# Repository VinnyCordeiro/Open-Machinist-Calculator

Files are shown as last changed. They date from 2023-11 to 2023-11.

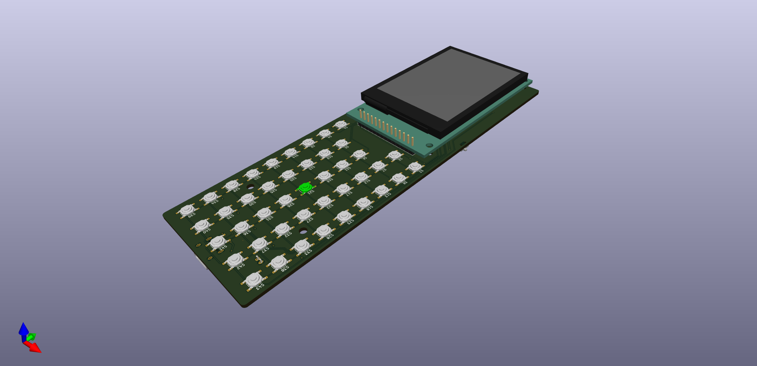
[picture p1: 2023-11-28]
documentation/Open_Machinist_Calculator.png

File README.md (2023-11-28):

# Open-Machinist-Calculator
Open Machinist Calculator, an open source hardware version of the Machinist Calc™ Pro calculator by Calculated Industries®

### FAQ
* ***Why?***

Because I'm interested in learning machining and that already-available calculator is too expensive for a hobbyist like me. So the idea is research all the formulas, code them in the calculator, and use it when needed.

* ***Why have you chosen the CERN Open Hardware Licence?***

Because as much as I love the GPL, it was created for Open Source **Software**. Open Source Hardware is an entirely different beast, with very different concerns and needs to be attended, there's even an [article](https://www.gnu.org/philosophy/free-hardware-designs.en.html) concerning that on the GNU website.

### TODO
* Start the code for real instead of a place holder. That also means researching all the formulas for each function, both for metric and imperial measurements. That'll be fun. 🙃
* Create a separate repository for the code and license under the GPL v3, the CERN licence is just for the hardware.
* The case is by no means water/dust proof, and that can be a huge problem with metallic dust from machining. That's something that needs improvement.

### UPDATES
November 28th, 2023: Initial public release.

<hr />
<table border="0px">
<th align="left">
&copy; Open Machinist Calculator 2023.
</th>
<tr>
<td>
This documentation describes Open Hardware and is licensed under the CERN Open Hardware Licence version 2 - Strongly Reciprocal.
</td>
</tr>
<tr>
<td>
You may redistribute and modify this documentation under the terms of the
CERN-OHL-S v2. (http://ohwr.org/cernohl). This documentation is distributed
WITHOUT ANY EXPRESS OR IMPLIED WARRANTY, INCLUDING OF
MERCHANTABILITY, SATISFACTORY QUALITY AND FITNESS FOR A
PARTICULAR PURPOSE. Please see the CERN-OHL-S v2 for applicable
conditions.
</td>
</tr>
</table>

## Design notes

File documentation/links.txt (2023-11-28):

Raspberry Pi Pico -- 4x4 Matrix Keypad and 1602 LCD Interface
https://www.instructables.com/Raspberry-Pi-Pico-4x4-Matrix-Keypad-and-1602-LCD-I/

Use Matrix Keypad with Raspberry PI Pico to get User Codes Input
https://peppe8o.com/use-matrix-keypad-with-raspberry-pi-pico-to-get-user-codes-input/

Raspberry Pi Pico Interrupts & Button Interfacing Tutorial Using MicroPython.
https://electrocredible.com/raspberry-pi-pico-external-interrupts-button-micropython/

ILI9341 TFT display with Arduino
https://electronoobs.com/eng_arduino_tut58.php

Color 320x240 TFT Touchscreen, ILI9341 Controller Chip (for reference)
https://www.pjrc.com/store/display_ili9341_touch.html

Arduino Calculator
https://projecthub.arduino.cc/123samridhgarg/arduino-calculator-bce0df

Arduino Calculator Using 4X4 Keypad 
https://www.instructables.com/Arduino-Calculator-Using-4X4-Keypad/

How to Make a Simple Arduino Uno Calculator
https://linuxhint.com/make-simple-calculator-arduino-uno/

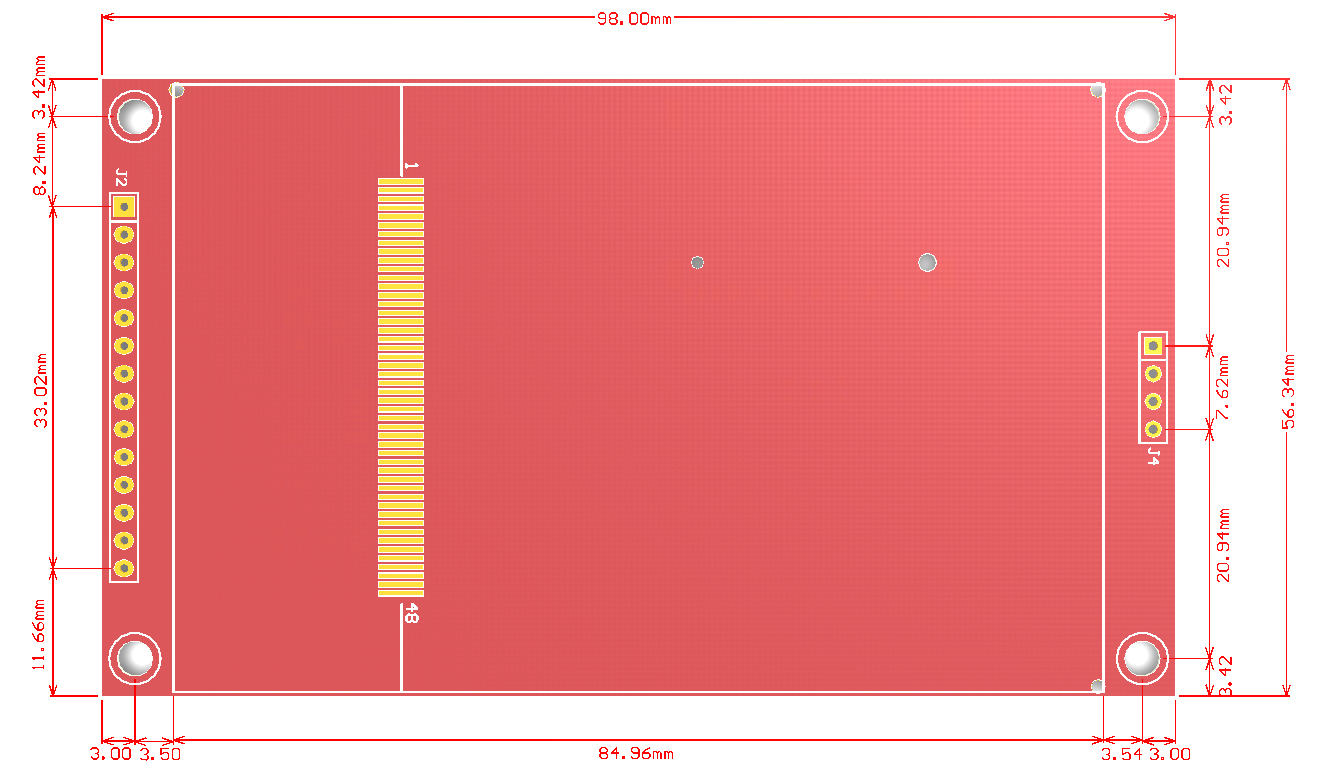
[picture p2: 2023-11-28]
documentation/elecrow-35inch-480x320-mcu-spi-serial-tft-lcd-module-display-dime.jpg

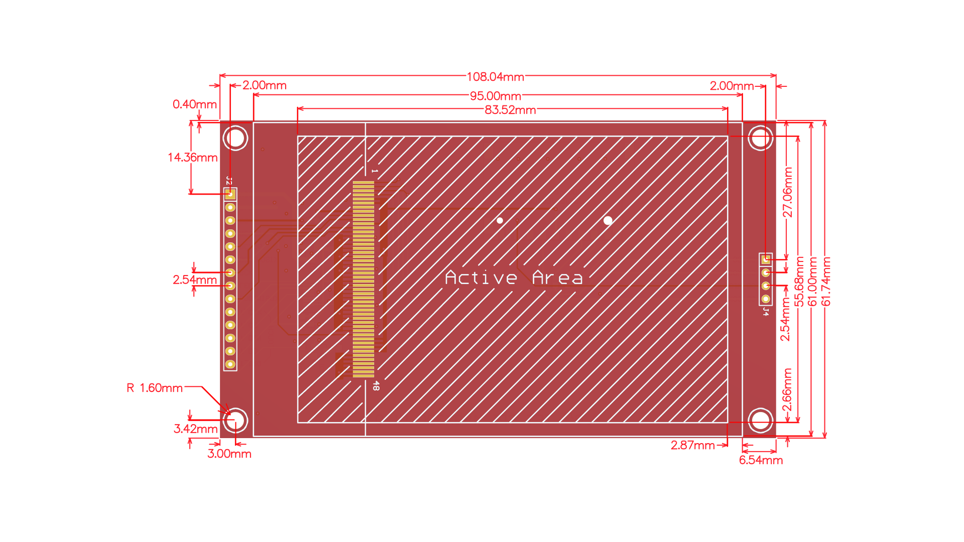
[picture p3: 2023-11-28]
documentation/4.0in_module.png

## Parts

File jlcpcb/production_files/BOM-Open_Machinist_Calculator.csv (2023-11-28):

Comment | Designator | Footprint | LCSC
0.1uF | C10,C12,C13,C18,C6,C7,C8,C9 | C_0603_1608Metric | C14663
MCP73831 | U4 | SOT-23-5 | C14879
1uF | C11,C14 | C_0603_1608Metric | C15849
10µF | C3,C4 | C_0805_2012Metric_Pad1.18x1.45mm_HandSolder | C15850
HRO-TYPE-C-31-M-12 | J1 | HRO-TYPE-C-31-M-12-HandSoldering | C165948
10k | R1,R14,R2,R3,R4,R5,R9 | R_0805_2012Metric_Pad1.20x1.40mm_HandSolder | C17414
0 | R8 | R_0805_2012Metric_Pad1.20x1.40mm_HandSolder | C17477
300k | R10,R11 | R_0805_2012Metric_Pad1.20x1.40mm_HandSolder | C17616
4.7µF | C5 | C_0805_2012Metric_Pad1.18x1.45mm_HandSolder | C1779
10uF | C15 | C_0603_1608Metric | C19702
RP2040 | U3 | QFN-56_EP_7x7_Pitch0.4mm | C2040
1K | R12,R17 | R_0603_1608Metric | C21190
LED_CHR | D2 | LED_0603_1608Metric | C2286
2K | R15 | R_0603_1608Metric | C22975
SW_RESET | SW1 | SW_SPST_B3U-1000P | C231329
27R | R18,R19 | R_0603_1608Metric | C25190
10K | R13,R20 | R_0603_1608Metric | C25804
AP2301B | Q2 | SOT-23-3 | C2763847
5.1k | R6,R7 | R_0805_2012Metric_Pad1.20x1.40mm_HandSolder | C27834
USBLC6-2P6 | U1 | SOT-666 | C2827693
1µF | C1 | C_0805_2012Metric_Pad1.18x1.45mm_HandSolder | C28323
~ | S1,S10,S11,S12,S13,S14,S15,S16,S17,S18,S19,S2,S20,S21,S22,S23,S24,S25,S26,S27,S28,S29,S3,S30,S31,S32,S33,S34,S35,S36,S37,S38,S39,S4,S40,S41,S42,S5,S6,S7,S8,S9 | TL3342 | C2886898
W25Q64JV | U5 | WSON-8-1EP_6x5mm_P1.27mm_EP3.4x4mm | C2940197
XC6220B331MR | U2 | SOT-23-5 | C3040644
12pF | C16,C17 | C_0603_1608Metric | C38523
100nF | C2 | C_0805_2012Metric_Pad1.18x1.45mm_HandSolder | C49678
DMG2301L | Q1 | SOT-23 | C508195
XYDBPCNANF-12MHZ | Y1 | Crystal_SMD_2520-4Pin_2.5x2.0mm | C521567
MBR0520 | D1 | D_SOD-123 | C77335
MK-11C04-G013 | SW2 | MK-11C04-G013 | C778185
Polyfuse | F1 | R_1206_3216Metric_Pad1.30x1.75mm_HandSolder | C910830
Conn_North | J4 | Castellated_1x10_P2.00mm_Vertical
Conn_01x02 | J2 | JST_PH_S2B-PH-K_1x02_P2.00mm_Horizontal
Conn_01x14 | J3 | PinHeader_1x14_P2.54mm_Vertical
Conn_South | J7 | Castellated_1x10_P2.00mm_Vertical
Conn_East | J6 | Castellated_1x10_P2.00mm_Vertical
Conn_West | J5 | Castellated_1x10_P2.00mm_Vertical

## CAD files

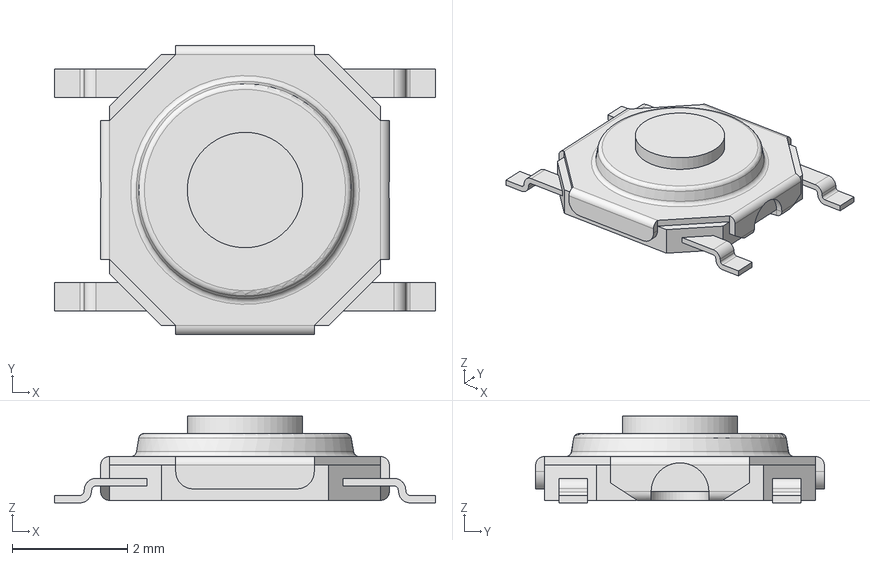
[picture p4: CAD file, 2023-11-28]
3d_models/TL3342FxxxQG.stp
6.60 x 5.00 x 1.50 mm

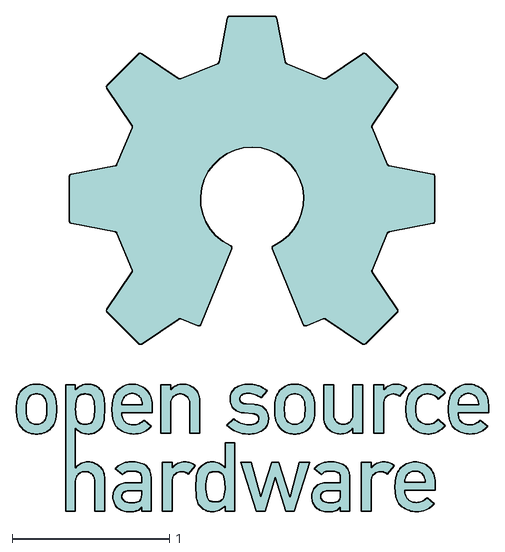
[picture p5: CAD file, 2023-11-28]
OSHW-Logo-R2000.dxf
3.00 x 3.15

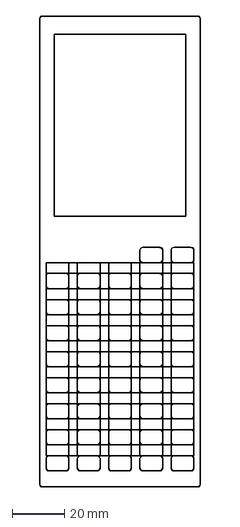
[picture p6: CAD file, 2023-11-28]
SVG/Front_label.dxf
61.8 x 180.8 mm

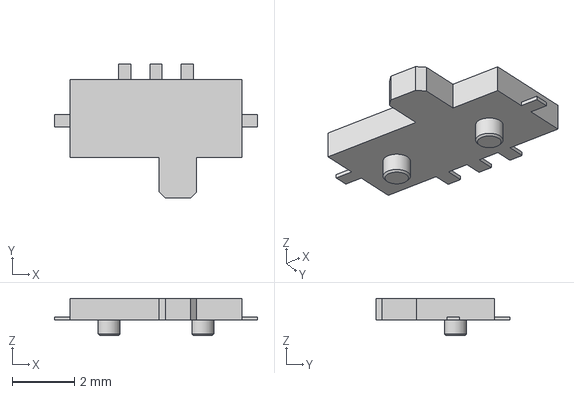
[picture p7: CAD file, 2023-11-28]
3d_models/G-Switch_MK-11C04-G013.step
6.50 x 4.30 x 1.20 mm

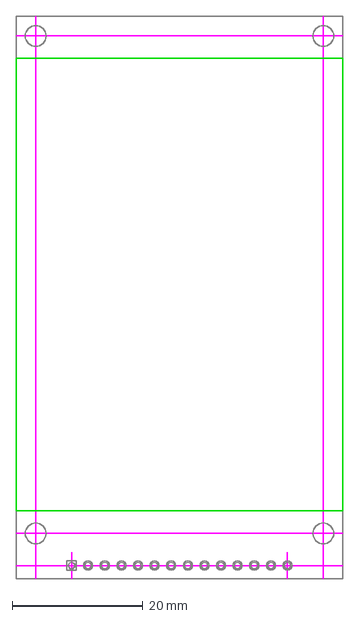
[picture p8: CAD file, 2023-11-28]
display_layout.dxf
50.0 x 86.0 mm

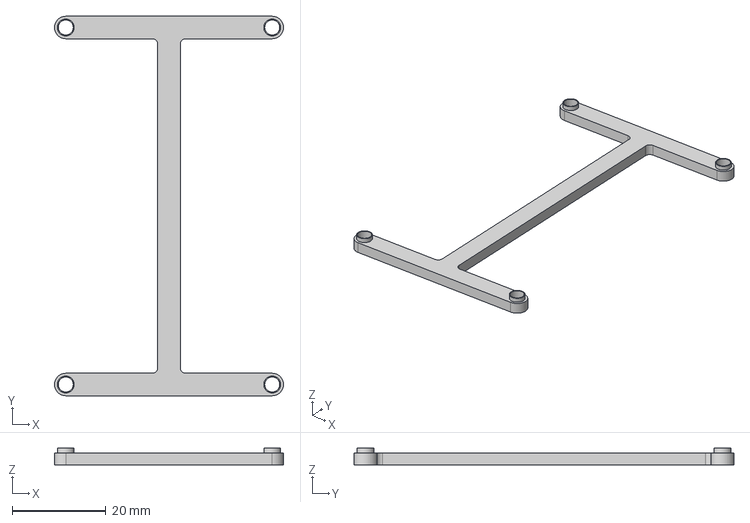
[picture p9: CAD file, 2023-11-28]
3d_models/Display_spacer.step
48.8 x 80.9 x 3.54 mm

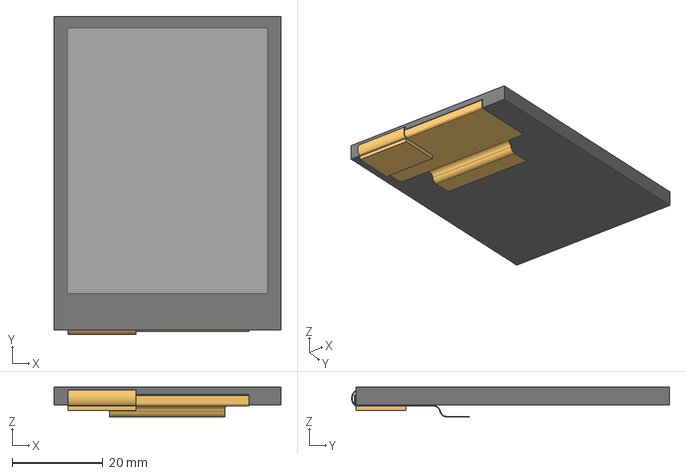
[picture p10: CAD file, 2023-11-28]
3d_models/280QV10_display.step
50.0 x 70.2 x 6.60 mm

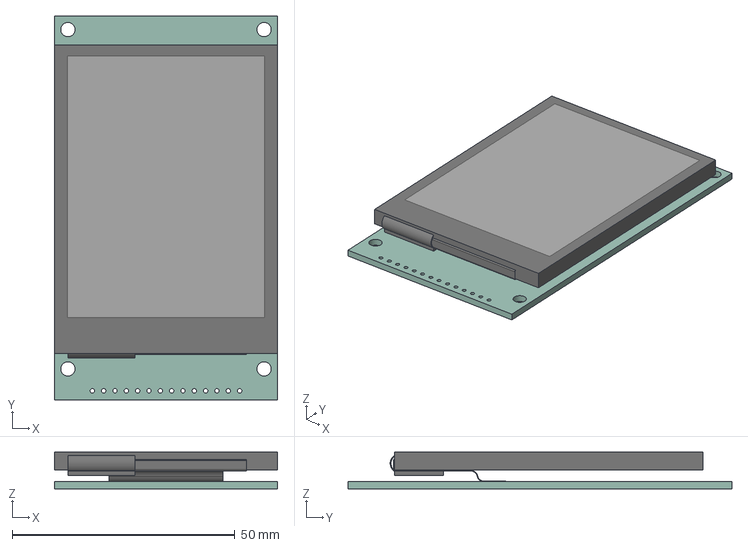
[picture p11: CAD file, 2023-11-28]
3d_models/display_module.step
50.0 x 86.0 x 8.20 mm

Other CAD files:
3d_models/G-Switch_MK-11C04-G013.f3d

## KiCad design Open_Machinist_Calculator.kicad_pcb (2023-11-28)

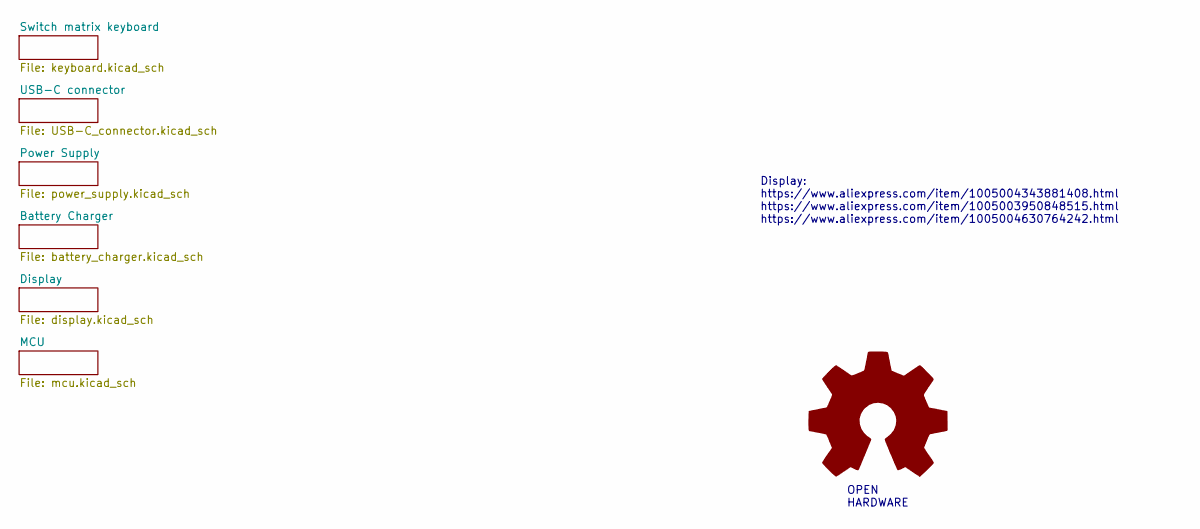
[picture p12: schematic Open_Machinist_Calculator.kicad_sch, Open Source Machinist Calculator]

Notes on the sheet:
OPEN HARDWARE
Display: https://www.aliexpress.com/item/1005004343881408.html https://www.aliexpress.com/item/1005003950848515.html https://www.aliexpress.com/item/1005004630764242.html

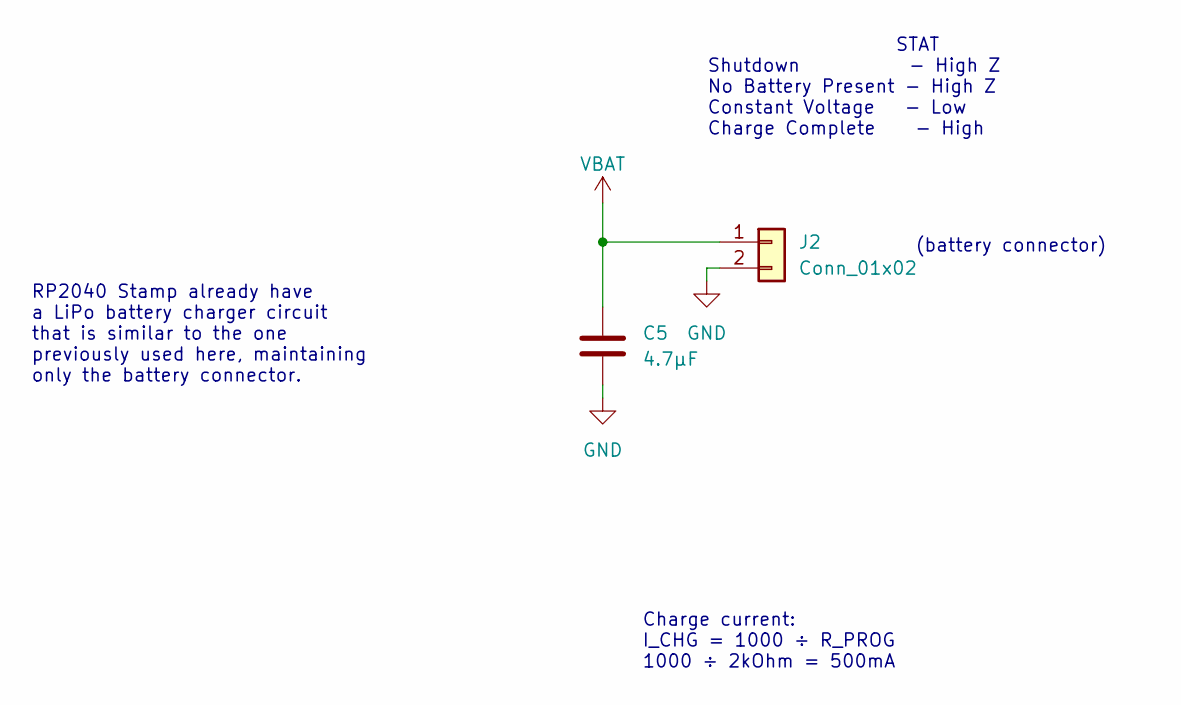
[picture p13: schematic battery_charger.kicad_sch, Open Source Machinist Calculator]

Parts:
C5: 4.7µF; C_0805_2012Metric_Pad1.18x1.45mm_HandSolder
J2: Conn_01x02; JST_PH_S2B-PH-K_1x02_P2.00mm_Horizontal

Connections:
GND: C5.2, J2.2; also elsewhere on the board
VBAT: C5.1, J2.1; also elsewhere on the board

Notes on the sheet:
(battery connector)
RP2040 Stamp already have a LiPo battery charger circuit that is similar to the one previously used here, maintaining only the battery connector.
STAT Shutdown - High Z No Battery Present - High Z Constant Voltage - Low Charge Complete - High
Charge current: I_CHG = 1000 ÷ R_PROG 1000 ÷ 2kOhm = 500mA

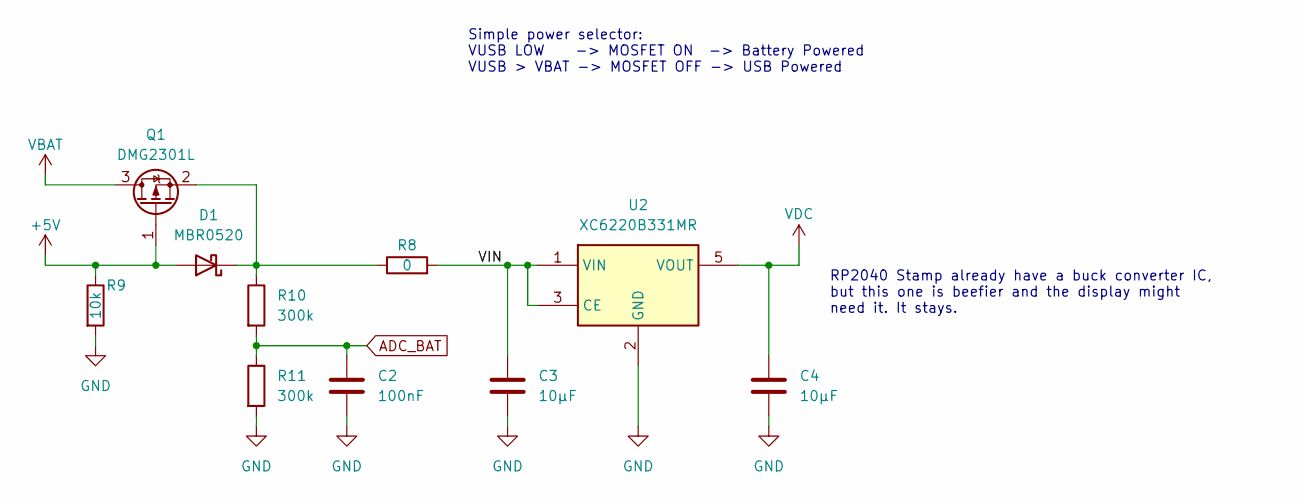
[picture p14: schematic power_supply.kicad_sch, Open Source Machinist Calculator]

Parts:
C2: 100nF; C_0805_2012Metric_Pad1.18x1.45mm_HandSolder
C3, C4: 10µF; C_0805_2012Metric_Pad1.18x1.45mm_HandSolder
D1: MBR0520; D_SOD-123
Q1: DMG2301L; SOT-23
R8: 0; R_0805_2012Metric_Pad1.20x1.40mm_HandSolder
R9: 10k; R_0805_2012Metric_Pad1.20x1.40mm_HandSolder
R10, R11: 300k; R_0805_2012Metric_Pad1.20x1.40mm_HandSolder
U2: XC6220B331MR; SOT-23-5

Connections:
+5V: D1.2 (A), Q1.1 (G), R9.1; also elsewhere on the board
/Power Supply/VIN: C3.1, R8.2, U2.1 (VIN), U2.3 (CE)
ADC_BAT: C2.1, R10.2, R11.1; also elsewhere on the board
GND: C2.2, C3.2, C4.2, R9.2, R11.2, U2.2 (GND); also elsewhere on the board
unnamed: D1.1 (K), Q1.2 (S), R8.1, R10.1
VBAT: Q1.3 (D); also elsewhere on the board
VDC: C4.1, U2.5 (VOUT); also elsewhere on the board

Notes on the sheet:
RP2040 Stamp already have a buck converter IC, but this one is beefier and the display might need it. It stays.
Simple power selector: VUSB LOW -> MOSFET ON -> Battery Powered VUSB > VBAT -> MOSFET OFF -> USB Powered

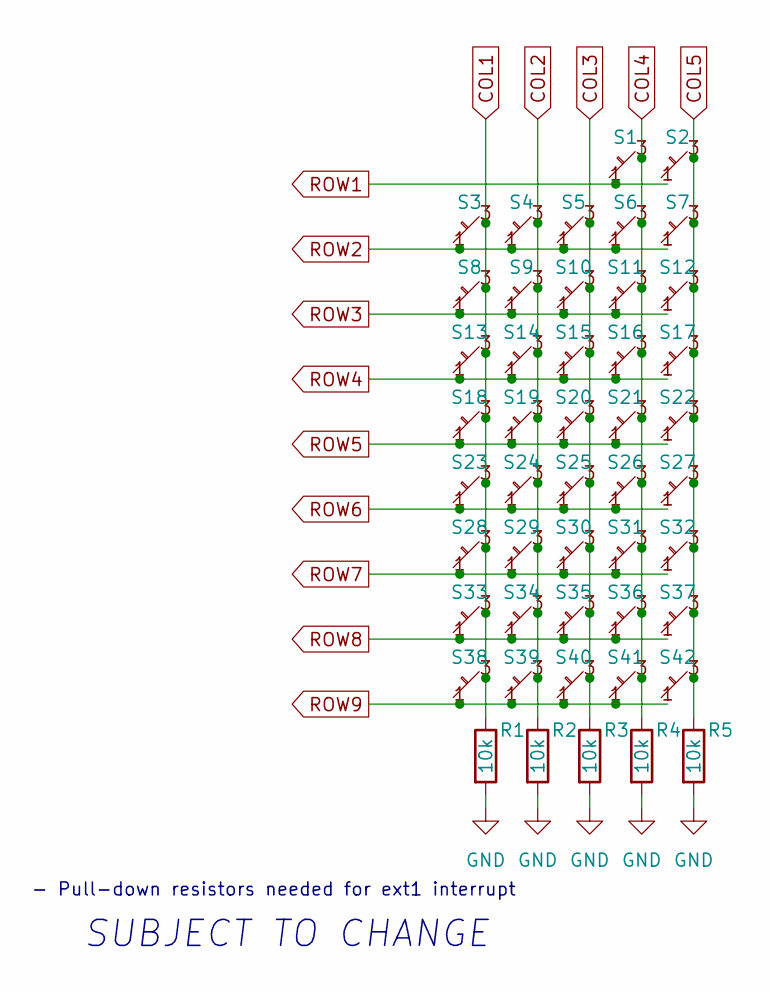
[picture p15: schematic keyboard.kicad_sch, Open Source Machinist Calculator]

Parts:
R1, R2, R3, R4, R5: 10k; R_0805_2012Metric_Pad1.20x1.40mm_HandSolder
S1, S2, S3, S4, S5, S6, S7, S8, S9, S10, S11, S12, S13, S14, S15, S16, S17, S18, S19, S20, S21, S22, S23, S24, S25, S26, S27, S28, S29, S30, S31, S32, S33, S34, S35, S36, S37, S38, S39, S40, S41, S42: TL3342

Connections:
COL1: R1.1, S3.3 (Pin2), S3.4 (Pin2), S8.3 (Pin2), S8.4 (Pin2), S13.3 (Pin2), S13.4 (Pin2), S18.3 (Pin2), S18.4 (Pin2), S23.3 (Pin2), S23.4 (Pin2), S28.3 (Pin2), S28.4 (Pin2), S33.3 (Pin2), S33.4 (Pin2), S38.3 (Pin2), S38.4 (Pin2); also elsewhere on the board
COL2: R2.1, S4.3 (Pin2), S4.4 (Pin2), S9.3 (Pin2), S9.4 (Pin2), S14.3 (Pin2), S14.4 (Pin2), S19.3 (Pin2), S19.4 (Pin2), S24.3 (Pin2), S24.4 (Pin2), S29.3 (Pin2), S29.4 (Pin2), S34.3 (Pin2), S34.4 (Pin2), S39.3 (Pin2), S39.4 (Pin2); also elsewhere on the board
COL3: R3.1, S5.3 (Pin2), S5.4 (Pin2), S10.3 (Pin2), S10.4 (Pin2), S15.3 (Pin2), S15.4 (Pin2), S20.3 (Pin2), S20.4 (Pin2), S25.3 (Pin2), S25.4 (Pin2), S30.3 (Pin2), S30.4 (Pin2), S35.3 (Pin2), S35.4 (Pin2), S40.3 (Pin2), S40.4 (Pin2); also elsewhere on the board
COL4: R4.1, S1.3 (Pin2), S1.4 (Pin2), S6.3 (Pin2), S6.4 (Pin2), S11.3 (Pin2), S11.4 (Pin2), S16.3 (Pin2), S16.4 (Pin2), S21.3 (Pin2), S21.4 (Pin2), S26.3 (Pin2), S26.4 (Pin2), S31.3 (Pin2), S31.4 (Pin2), S36.3 (Pin2), S36.4 (Pin2), S41.3 (Pin2), S41.4 (Pin2); also elsewhere on the board
COL5: R5.1, S2.3 (Pin2), S2.4 (Pin2), S7.3 (Pin2), S7.4 (Pin2), S12.3 (Pin2), S12.4 (Pin2), S17.3 (Pin2), S17.4 (Pin2), S22.3 (Pin2), S22.4 (Pin2), S27.3 (Pin2), S27.4 (Pin2), S32.3 (Pin2), S32.4 (Pin2), S37.3 (Pin2), S37.4 (Pin2), S42.3 (Pin2), S42.4 (Pin2); also elsewhere on the board
GND: R1.2, R2.2, R3.2, R4.2, R5.2; also elsewhere on the board
ROW1: S1.1 (Pin1), S1.2 (Pin1), S2.1 (Pin1), S2.2 (Pin1); also elsewhere on the board
ROW2: S3.1 (Pin1), S3.2 (Pin1), S4.1 (Pin1), S4.2 (Pin1), S5.1 (Pin1), S5.2 (Pin1), S6.1 (Pin1), S6.2 (Pin1), S7.1 (Pin1), S7.2 (Pin1); also elsewhere on the board
ROW3: S8.1 (Pin1), S8.2 (Pin1), S9.1 (Pin1), S9.2 (Pin1), S10.1 (Pin1), S10.2 (Pin1), S11.1 (Pin1), S11.2 (Pin1), S12.1 (Pin1), S12.2 (Pin1); also elsewhere on the board
ROW4: S13.1 (Pin1), S13.2 (Pin1), S14.1 (Pin1), S14.2 (Pin1), S15.1 (Pin1), S15.2 (Pin1), S16.1 (Pin1), S16.2 (Pin1), S17.1 (Pin1), S17.2 (Pin1); also elsewhere on the board
ROW5: S18.1 (Pin1), S18.2 (Pin1), S19.1 (Pin1), S19.2 (Pin1), S20.1 (Pin1), S20.2 (Pin1), S21.1 (Pin1), S21.2 (Pin1), S22.1 (Pin1), S22.2 (Pin1); also elsewhere on the board
ROW6: S23.1 (Pin1), S23.2 (Pin1), S24.1 (Pin1), S24.2 (Pin1), S25.1 (Pin1), S25.2 (Pin1), S26.1 (Pin1), S26.2 (Pin1), S27.1 (Pin1), S27.2 (Pin1); also elsewhere on the board
ROW7: S28.1 (Pin1), S28.2 (Pin1), S29.1 (Pin1), S29.2 (Pin1), S30.1 (Pin1), S30.2 (Pin1), S31.1 (Pin1), S31.2 (Pin1), S32.1 (Pin1), S32.2 (Pin1); also elsewhere on the board
ROW8: S33.1 (Pin1), S33.2 (Pin1), S34.1 (Pin1), S34.2 (Pin1), S35.1 (Pin1), S35.2 (Pin1), S36.1 (Pin1), S36.2 (Pin1), S37.1 (Pin1), S37.2 (Pin1); also elsewhere on the board
ROW9: S38.1 (Pin1), S38.2 (Pin1), S39.1 (Pin1), S39.2 (Pin1), S40.1 (Pin1), S40.2 (Pin1), S41.1 (Pin1), S41.2 (Pin1), S42.1 (Pin1), S42.2 (Pin1); also elsewhere on the board

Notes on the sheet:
- Pull-down resistors needed for ext1 interrupt
SUBJECT TO CHANGE

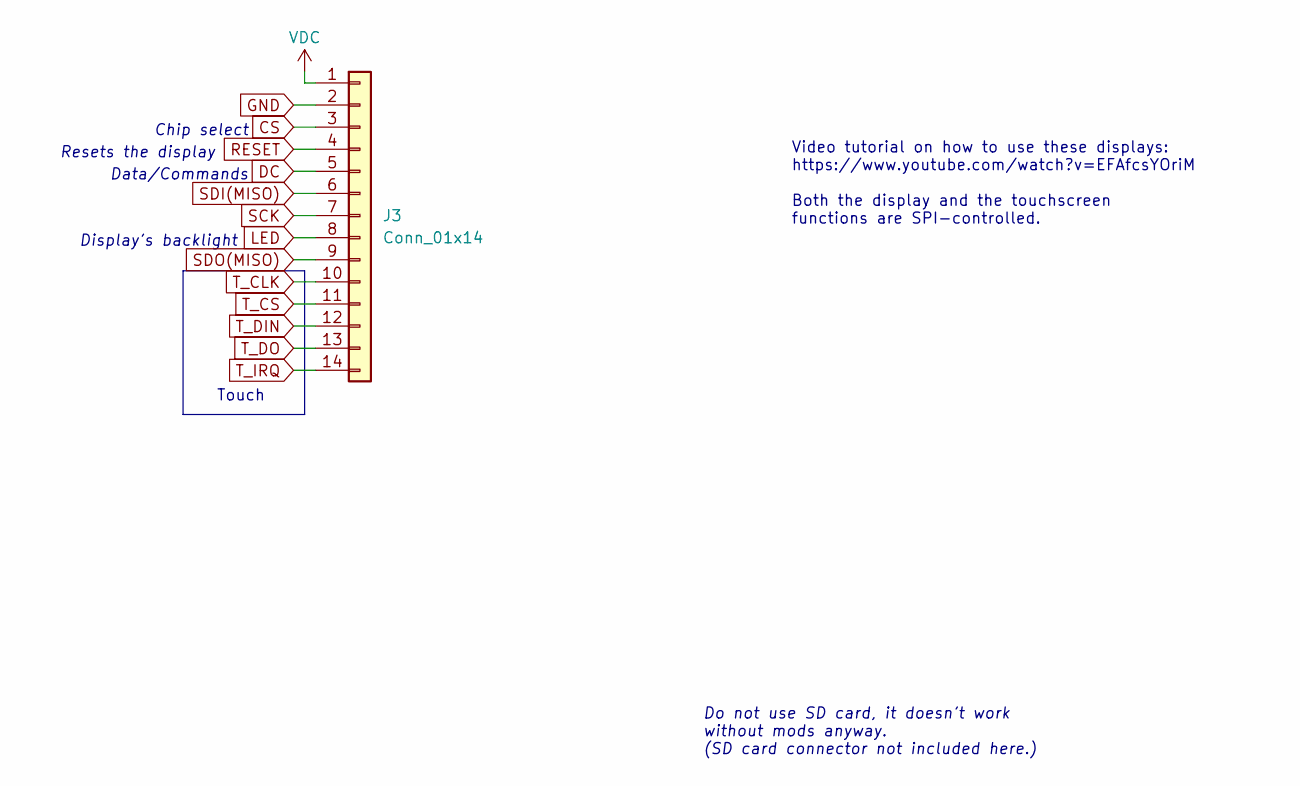
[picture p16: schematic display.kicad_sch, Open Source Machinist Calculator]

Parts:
J3: Conn_01x14; PinHeader_1x14_P2.54mm_Vertical

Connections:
CS: J3.3; also elsewhere on the board
DC: J3.5; also elsewhere on the board
GND: J3.2; also elsewhere on the board
LED: J3.8; also elsewhere on the board
RESET: J3.4; also elsewhere on the board
SCK: J3.7; also elsewhere on the board
SDI(MISO): J3.6; also elsewhere on the board
SDO(MISO): J3.9; also elsewhere on the board
T_CLK: J3.10; also elsewhere on the board
T_CS: J3.11; also elsewhere on the board
T_DIN: J3.12; also elsewhere on the board
T_DO: J3.13; also elsewhere on the board
T_IRQ: J3.14; also elsewhere on the board
VDC: J3.1; also elsewhere on the board

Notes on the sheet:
Touch
Video tutorial on how to use these displays: https://www.youtube.com/watch?v=EFAfcsYOriM Both the display and the touchscreen functions are SPI-controlled.
Data/Commands
Resets the display
Display's backlight
Chip select
Do not use SD card, it doesn't work without mods anyway. (SD card connector not included here.)

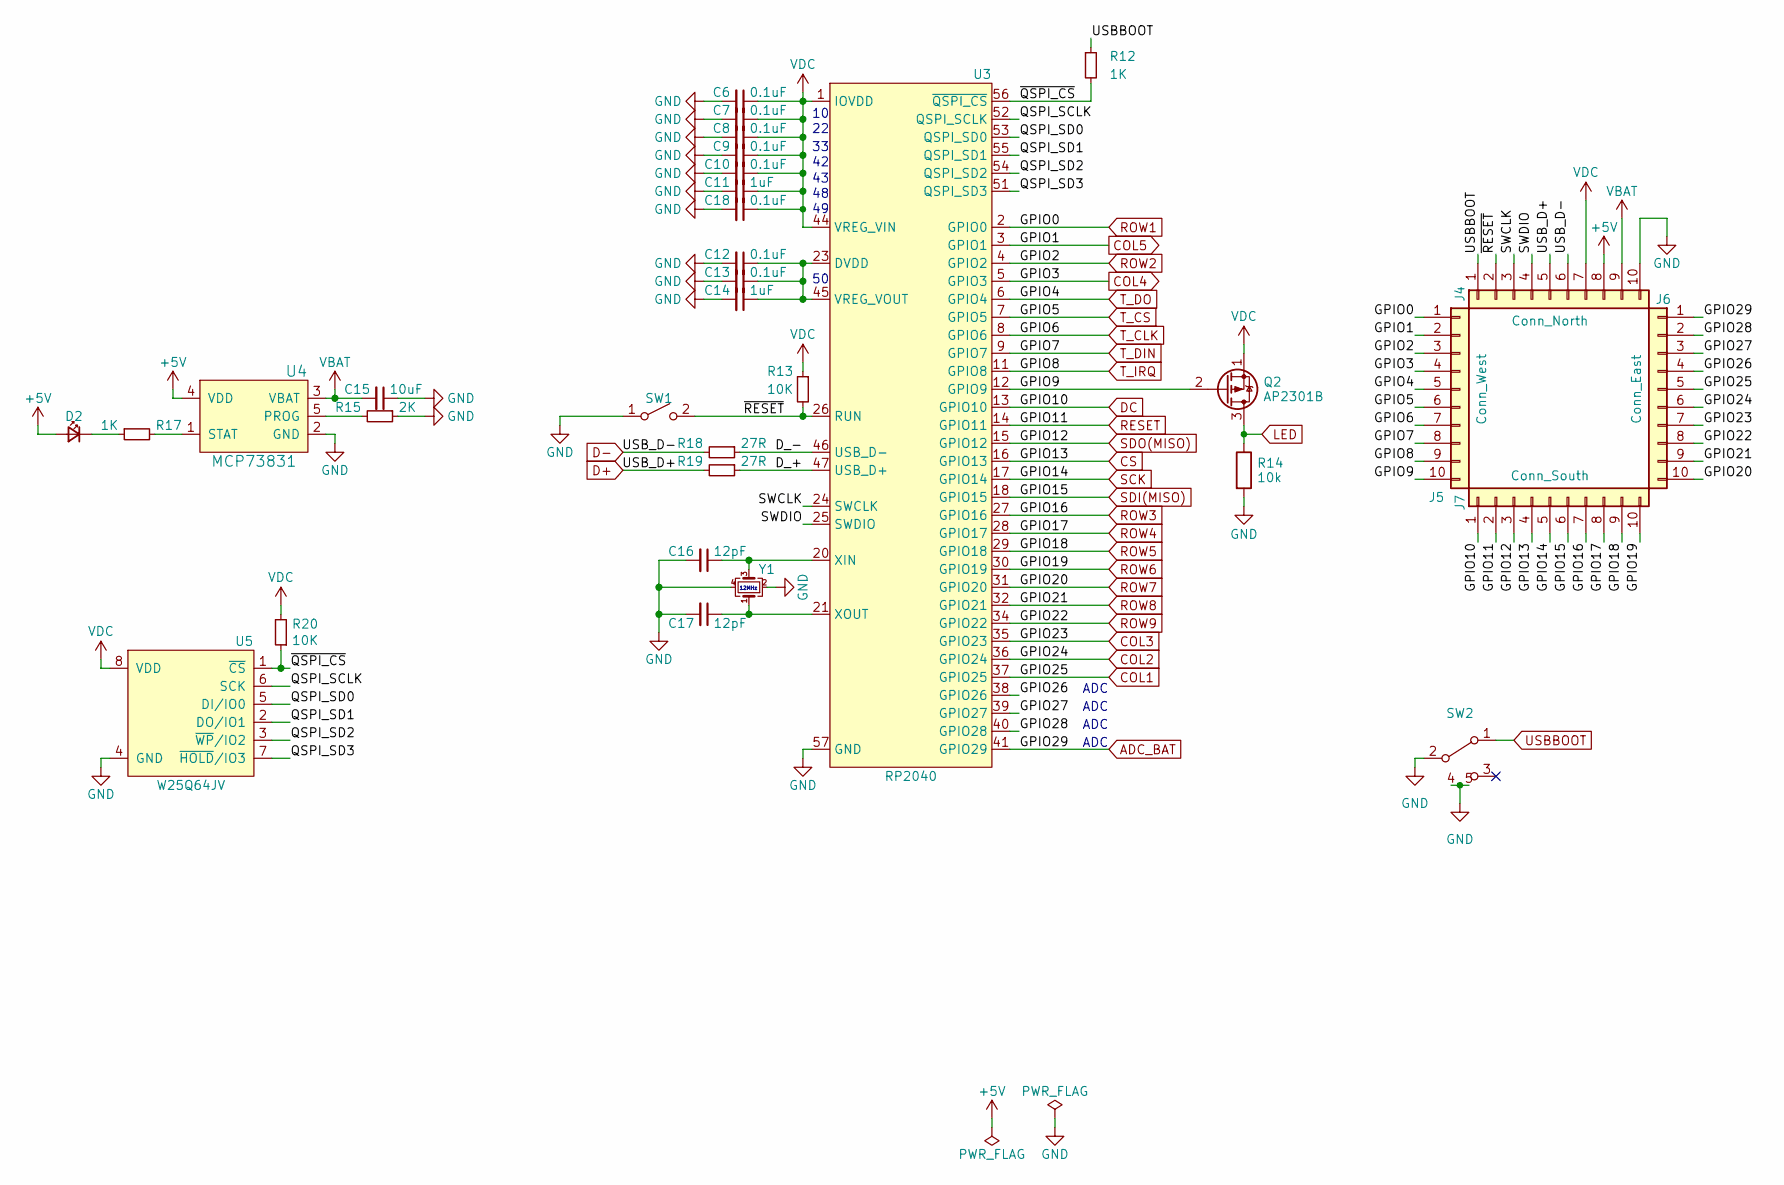
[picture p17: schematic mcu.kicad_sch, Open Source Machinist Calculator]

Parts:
C6, C7, C8, C9, C10, C12, C13, C18: 0.1uF; C_0603_1608Metric
C11, C14: 1uF; C_0603_1608Metric
C15: 10uF; C_0603_1608Metric
C16, C17: 12pF; C_0603_1608Metric
D2: LED_CHR; LED_0603_1608Metric
J4: Conn_North; Castellated_1x10_P2.00mm_Vertical
J5: Conn_West; Castellated_1x10_P2.00mm_Vertical
J6: Conn_East; Castellated_1x10_P2.00mm_Vertical
J7: Conn_South; Castellated_1x10_P2.00mm_Vertical
Q2: AP2301B; SOT-23-3; LCSC Part# C2763847
R12, R17: 1K; R_0603_1608Metric
R13, R20: 10K; R_0603_1608Metric
R14: 10k; R_0805_2012Metric_Pad1.20x1.40mm_HandSolder
R15: 2K; R_0603_1608Metric
R18, R19: 27R; R_0603_1608Metric
SW1: SW_RESET; SW_SPST_B3U-1000P
SW2: MK-11C04-G013; LCSC Part# C778185
U3: RP2040; QFN-56_EP_7x7_Pitch0.4mm
U4: MCP73831; SOT-23-5; LCSC C14879
U5: W25Q64JV; WSON-8-1EP_6x5mm_P1.27mm_EP3.4x4mm
Y1: XYDBPCNANF-12MHZ; Crystal_SMD_2520-4Pin_2.5x2.0mm; LCSC C521567

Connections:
+5V: D2.2 (A), J4.8, U4.4 (VDD); also elsewhere on the board
/MCU/D_+: R19.1, U3.47 (USB_D+)
/MCU/D_-: R18.1, U3.46 (USB_D-)
/MCU/GPIO9: J5.10, Q2.2 (G), U3.12 (GPIO9)
/MCU/GPIO26: J6.4, U3.38 (GPIO26)
/MCU/GPIO27: J6.3, U3.39 (GPIO27)
/MCU/GPIO28: J6.2, U3.40 (GPIO28)
/MCU/QSPI_SCLK: U3.52 (QSPI_SCLK), U5.6 (SCK)
/MCU/QSPI_SD0: U3.53 (QSPI_SD0), U5.5 (DI/IO0)
/MCU/QSPI_SD1: U3.55 (QSPI_SD1), U5.2 (DO/IO1)
/MCU/QSPI_SD2: U3.54 (QSPI_SD2), U5.3 (~WP/IO2)
/MCU/QSPI_SD3: U3.51 (QSPI_SD3), U5.7 (~HOLD/IO3)
/MCU/SWCLK: J4.3, U3.24 (SWCLK)
/MCU/SWDIO: J4.4, U3.25 (SWDIO)
/MCU/~QSPI_CS: R12.2, R20.1, U3.56 (~QSPI_CS), U5.1 (~CS)
/MCU/~RESET: J4.2, R13.2, SW1.2 (B), U3.26 (RUN)
ADC_BAT: J6.1, U3.41 (GPIO29); also elsewhere on the board
COL1: J6.5, U3.37 (GPIO25); also elsewhere on the board
COL2: J6.6, U3.36 (GPIO24); also elsewhere on the board
COL3: J6.7, U3.35 (GPIO23); also elsewhere on the board
COL4: J5.4, U3.5 (GPIO3); also elsewhere on the board
COL5: J5.2, U3.3 (GPIO1); also elsewhere on the board
CS: J7.4, U3.16 (GPIO13); also elsewhere on the board
D+: J4.5, R19.2; also elsewhere on the board
D-: J4.6, R18.2; also elsewhere on the board
DC: J7.1, U3.13 (GPIO10); also elsewhere on the board
GND: C6.2, C7.2, C8.2, C9.2, C10.2, C11.2, C12.2, C13.2, C14.2, C15.1, C16.2, C17.2, C18.2, J4.10, R14.2, R15.1, SW1.1 (A), SW2.2 (B), SW2.4, SW2.5 (4), U3.19 (TESTEN), U3.57 (GND), U4.2 (GND), U5.4 (GND), U5.9 (GND), Y1.2, Y1.4; also elsewhere on the board
LED: Q2.3 (D), R14.1; also elsewhere on the board
unnamed: D2.1 (K), R17.1
unnamed: C12.1, C13.1, C14.1, U3.23 (DVDD), U3.45 (VREG_VOUT), U3.50 (DVDD)
unnamed: C16.1, U3.20 (XIN), Y1.3
unnamed: C17.1, U3.21 (XOUT), Y1.1
unnamed: R15.2, U4.5 (PROG)
unnamed: R17.2, U4.1 (STAT)
RESET: J7.2, U3.14 (GPIO11); also elsewhere on the board
ROW1: J5.1, U3.2 (GPIO0); also elsewhere on the board
ROW2: J5.3, U3.4 (GPIO2); also elsewhere on the board
ROW3: J7.7, U3.27 (GPIO16); also elsewhere on the board
ROW4: J7.8, U3.28 (GPIO17); also elsewhere on the board
ROW5: J7.9, U3.29 (GPIO18); also elsewhere on the board
ROW6: J7.10, U3.30 (GPIO19); also elsewhere on the board
ROW7: J6.10, U3.31 (GPIO20); also elsewhere on the board
ROW8: J6.9, U3.32 (GPIO21); also elsewhere on the board
ROW9: J6.8, U3.34 (GPIO22); also elsewhere on the board
SCK: J7.5, U3.17 (GPIO14); also elsewhere on the board
SDI(MISO): J7.6, U3.18 (GPIO15); also elsewhere on the board
SDO(MISO): J7.3, U3.15 (GPIO12); also elsewhere on the board
T_CLK: J5.7, U3.8 (GPIO6); also elsewhere on the board
T_CS: J5.6, U3.7 (GPIO5); also elsewhere on the board
T_DIN: J5.8, U3.9 (GPIO7); also elsewhere on the board
T_DO: J5.5, U3.6 (GPIO4); also elsewhere on the board
T_IRQ: J5.9, U3.11 (GPIO8); also elsewhere on the board
USBBOOT: J4.1, R12.1, SW2.1 (A)
VBAT: C15.2, J4.9, U4.3 (VBAT); also elsewhere on the board
VDC: C6.1, C7.1, C8.1, C9.1, C10.1, C11.1, C18.1, J4.7, Q2.1 (S), R13.1, R20.2, U3.1 (IOVDD), U3.10 (IOVDD), U3.22 (IOVDD), U3.33 (IOVDD), U3.42 (IOVDD), U3.43 (ADC_AVDD), U3.44 (VREG_VIN), U3.48 (USB_VDD), U3.49 (IOVDD), U5.8 (VDD); also elsewhere on the board

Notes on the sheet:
ADC
12MHz

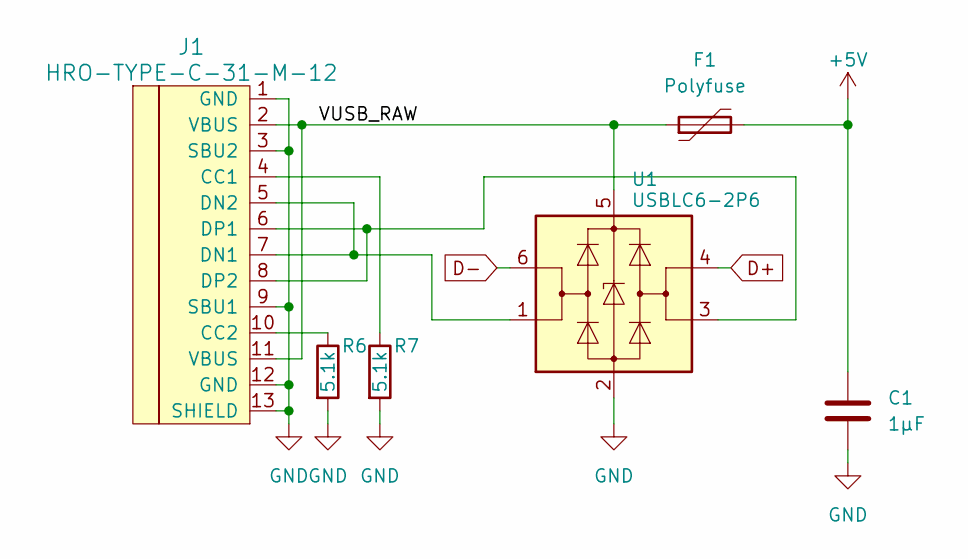
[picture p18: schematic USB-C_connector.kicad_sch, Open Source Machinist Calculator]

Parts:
C1: 1µF; C_0805_2012Metric_Pad1.18x1.45mm_HandSolder
F1: Polyfuse; R_1206_3216Metric_Pad1.30x1.75mm_HandSolder
J1: HRO-TYPE-C-31-M-12; HRO-TYPE-C-31-M-12-HandSoldering
R6, R7: 5.1k; R_0805_2012Metric_Pad1.20x1.40mm_HandSolder
U1: USBLC6-2P6; SOT-666

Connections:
+5V: C1.1, F1.2; also elsewhere on the board
/USB-C connector/VUSB_RAW: F1.1, J1.2 (VBUS), J1.11 (VBUS), U1.5 (VBUS)
D+: U1.4 (I/O2); also elsewhere on the board
D-: U1.6 (I/O1); also elsewhere on the board
GND: C1.2, J1.1 (GND), J1.3 (SBU2), J1.9 (SBU1), J1.12 (GND), J1.13 (SHIELD), R6.2, R7.2, U1.2 (GND); also elsewhere on the board
unnamed: J1.4 (CC1), R7.1
unnamed: J1.10 (CC2), R6.1
unnamed: J1.5 (DN2), J1.7 (DN1), U1.1 (I/O1)
unnamed: J1.6 (DP1), J1.8 (DP2), U1.3 (I/O2)

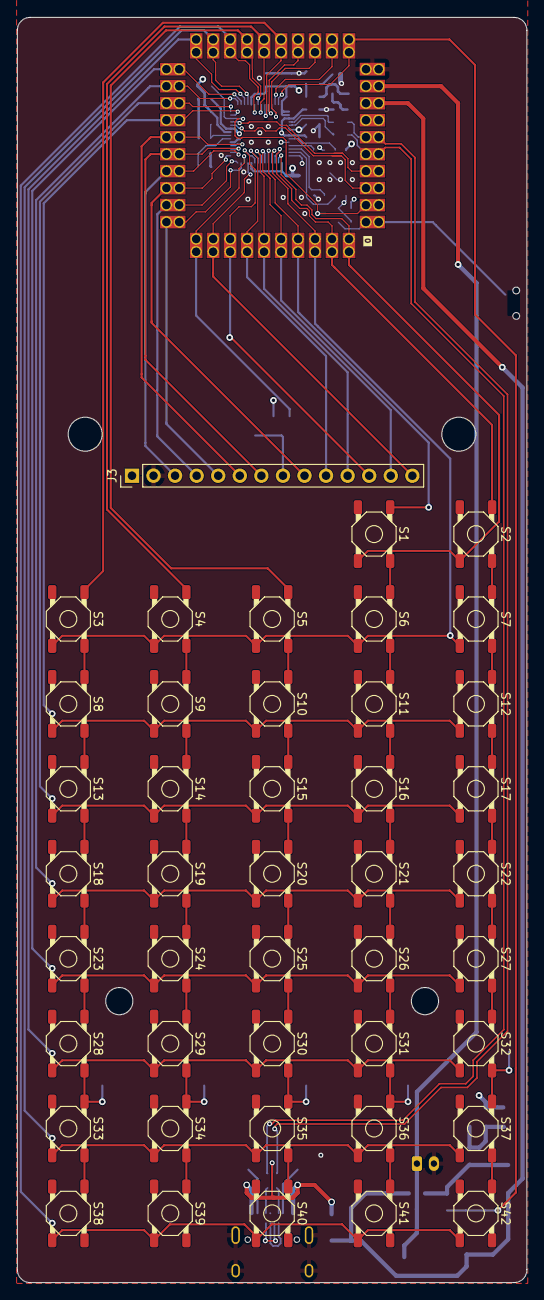
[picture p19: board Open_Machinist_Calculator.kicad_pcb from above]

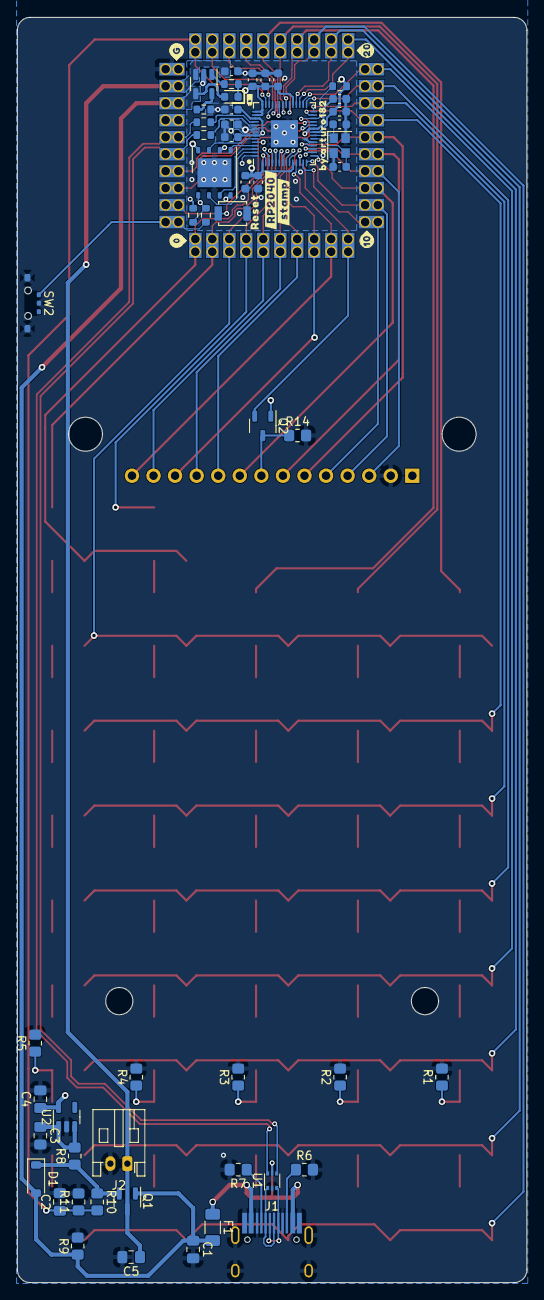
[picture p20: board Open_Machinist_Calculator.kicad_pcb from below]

Board: 4 copper layers, 60.0 x 149.0 mm, 99 parts (56 on the bottom side), 62 nets.

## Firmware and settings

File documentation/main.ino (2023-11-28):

/* 
 * Open Source Machinist Calculator
 * (Based on Arduino Keypad calculator Program: https://projecthub.arduino.cc/123samridhgarg/arduino-calculator-bce0df)
 */

#include "SPI.h"
#include "Adafruit_GFX.h"
#include "Adafruit_ILI9341.h"
#include <Keypad.h> //Header file for Keypad from https://github.com/Chris--A/Keypad

const byte ROWS = 9;
const byte COLS = 5;

// Define  the Keymap
char keys[ROWS][COLS] = {

  {     '',    '',        '',         'Off',        'On/C'},
  {   'Vc',   'n',      'Vf','Bolt_Pattern', 'Thread_Size'},
  {    'z',  'fz',      'fn',    'Diameter',  'Drill_Size'},
  {    'x',   'y',       'r',       'Angle',           '%'},
  {   'mm','inch','Fraction',        'mils',   'Backspace'},
  { 'Conv',   '7',       '8',           '9',      'Divide'},
  { 'Stor',   '4',       '5',           '6',    'Multiply'},
  {  'Rcl',   '1',       '2',           '3', 'Subtraction'},
  {   'M+',   '0',     'Dot',       'Equal',    'Addition'}

};

// Everything from here is unedited from the example.

byte rowPins[ROWS]  = { 0, 1, 2, 3 };// Connect keypad ROW0, ROW1, ROW2 and ROW3 to these Arduino pins.
byte  colPins[COLS] = { 4, 5, 6, 7 }; // Connect keypad COL0, COL1 and COL2 to these Arduino  pins.

Keypad kpd = Keypad( makeKeymap(keys), rowPins, colPins, ROWS, COLS  ); //  Create the Keypad

const int rs = 8, en = 9, d4 = 10, d5 = 11, d6 =  12, d7 = 13; //Pins to which LCD is connected
LiquidCrystal lcd(rs, en, d4, d5,  d6, d7);

 long Num1,Num2,Number;
 char key,action;
 boolean result  = false;
 
void setup() {
  lcd.begin(16, 2); //We are using a 16*2 LCD  display
  lcd.print("DIY Calculator"); //Display a intro message
  lcd.setCursor(0,  1);   // set the cursor to column 0, line 1
  lcd.print("-CircuitDigest");  //Display a intro message 

   delay(2000); //Wait for display to show info
    lcd.clear(); //Then clean it
}

void loop() {
  
key = kpd.getKey();  //storing pressed key value in a char

if (key!=NO_KEY)
DetectButtons();

if  (result==true)
CalculateResult();

DisplayResult();   
}

void  DetectButtons()
{ 
     lcd.clear(); //Then clean it
    if (key=='*')  //If cancel Button is pressed
    {Serial.println ("Button Cancel"); Number=Num1=Num2=0;  result=false;}
    
     if (key == '1') //If Button 1 is pressed
    {Serial.println  ("Button 1"); 
    if (Number==0)
    Number=1;
    else
    Number  = (Number*10) + 1; //Pressed twice
    }
    
     if (key == '4') //If  Button 4 is pressed
    {Serial.println ("Button 4"); 
    if (Number==0)
    Number=4;
    else
    Number = (Number*10) + 4; //Pressed twice
    }
    
     if (key == '7') //If Button 7 is pressed
    {Serial.println ("Button  7");
    if (Number==0)
    Number=7;
    else
    Number = (Number*10)  + 7; //Pressed twice
    } 
  

    if (key == '0')
    {Serial.println  ("Button 0"); //Button 0 is Pressed
    if (Number==0)
    Number=0;
    else
    Number = (Number*10) + 0; //Pressed twice
    }
    
     if  (key == '2') //Button 2 is Pressed
    {Serial.println ("Button 2"); 
     if  (Number==0)
    Number=2;
    else
    Number = (Number*10) + 2; //Pressed  twice
    }
    
     if (key == '5')
    {Serial.println ("Button  5"); 
     if (Number==0)
    Number=5;
    else
    Number = (Number*10)  + 5; //Pressed twice
    }
    
     if (key == '8')
    {Serial.println  ("Button 8"); 
     if (Number==0)
    Number=8;
    else
    Number  = (Number*10) + 8; //Pressed twice
    }   
  

    if (key == '#')
    {Serial.println ("Button Equal"); 
    Num2=Number;
    result = true;
    }
    
     if (key == '3')
    {Serial.println ("Button 3"); 
     if (Number==0)
    Number=3;
    else
    Number = (Number*10) + 3;  //Pressed twice
    }
    
     if (key == '6')
    {Serial.println  ("Button 6"); 
    if (Number==0)
    Number=6;
    else
    Number  = (Number*10) + 6; //Pressed twice
    }
    
     if (key == '9')
    {Serial.println ("Button 9");
    if (Number==0)
    Number=9;
    else
    Number = (Number*10) + 9; //Pressed twice
    }  

      if (key ==  'A' || key == 'B' || key == 'C' || key == 'D') //Detecting Buttons on Column 4
  {
    Num1 = Number;    
    Number =0;
    if (key == 'A')
    {Serial.println  ("Addition"); action = '+';}
     if (key == 'B')
    {Serial.println ("Subtraction");  action = '-'; }
     if (key == 'C')
    {Serial.println ("Multiplication");  action = '*';}
     if (key == 'D')
    {Serial.println ("Devesion"); action  = '/';}  

    delay(100);
  }
  
}

void CalculateResult()
{
  if (action=='+')
    Number = Num1+Num2;

  if (action=='-')
    Number  = Num1-Num2;

  if (action=='*')
    Number = Num1*Num2;

  if (action=='/')
    Number = Num1/Num2; 
}

void DisplayResult()
{
  lcd.setCursor(0,  0);   // set the cursor to column 0, line 1
  lcd.print(Num1); lcd.print(action);  lcd.print(Num2); 
  
  if (result==true)
  {lcd.print(" ="); lcd.print(Number);}  //Display the result
  
  lcd.setCursor(0, 1);   // set the cursor to column  0, line 1
  lcd.print(Number); //Display the result
}

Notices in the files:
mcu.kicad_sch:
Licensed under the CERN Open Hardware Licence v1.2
